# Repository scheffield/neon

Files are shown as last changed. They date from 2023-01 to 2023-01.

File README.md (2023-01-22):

# Neon

Neon is a remote controllable RGB light meant for video shots and life streaming. It's build around the ESP32-S2 and addressable RGB lights like the WS2812 or SK6812. This repository contains all the files to build your own version.

If you haven't go check out the build and some more info in this YouTube video:

Neon YouTube video (http://www.youtube.com/watch?v=w3ysH9Jxcy4 "Neon | PCB design, CAD and Code")

## Directory structure
```
$project_root/
├── cad/ ........... open with Fusion360
├── code/
│   ├── baords/ .... board config
│   ├── data/ ...... compiled website
│   ├── src/ ....... code for ESP32
│   ├── variants ... particion table
│   └── web/ ....... web UI
├── pcb/ ........... open with KiCad
└── stl/ ........... for 3D printing
```

## Web UI

### setup
```bash
cd web
npm i
```

### develop
```bash
npm run dev
```

### build
```bash
npm run webpack
cp dist/index.html ../data
pio run --target uploadfs
```

The last step is assuming that PlatformIO is installed and available as `pio`.

## BOM
Appart from the BOM for the PCB which can be exported from KiCad, the following parts are needed:

**BOM**
| Part | Amount |
|---|---|
| [1/4"*20 Threaded Heat Set Inserts](https://www.amazon.com.au/dp/B077P4M1CM) | 1 |
| [3-pin LiPo Battery 6000mAh](https://core-electronics.com.au/3-pin-lipo-battery-for-pijuice-6000mah.html) | 1 |

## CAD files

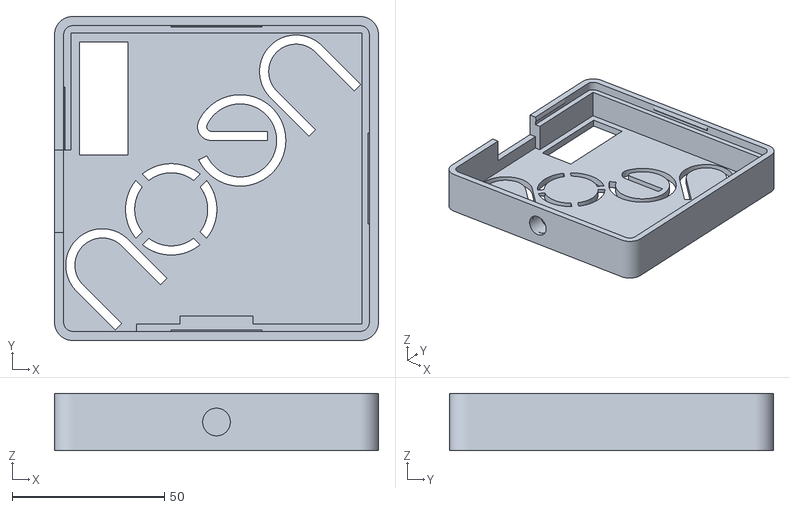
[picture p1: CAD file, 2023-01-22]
stl/case.stl
106.4 x 106.4 x 18.9

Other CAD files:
cad/neon.f3z

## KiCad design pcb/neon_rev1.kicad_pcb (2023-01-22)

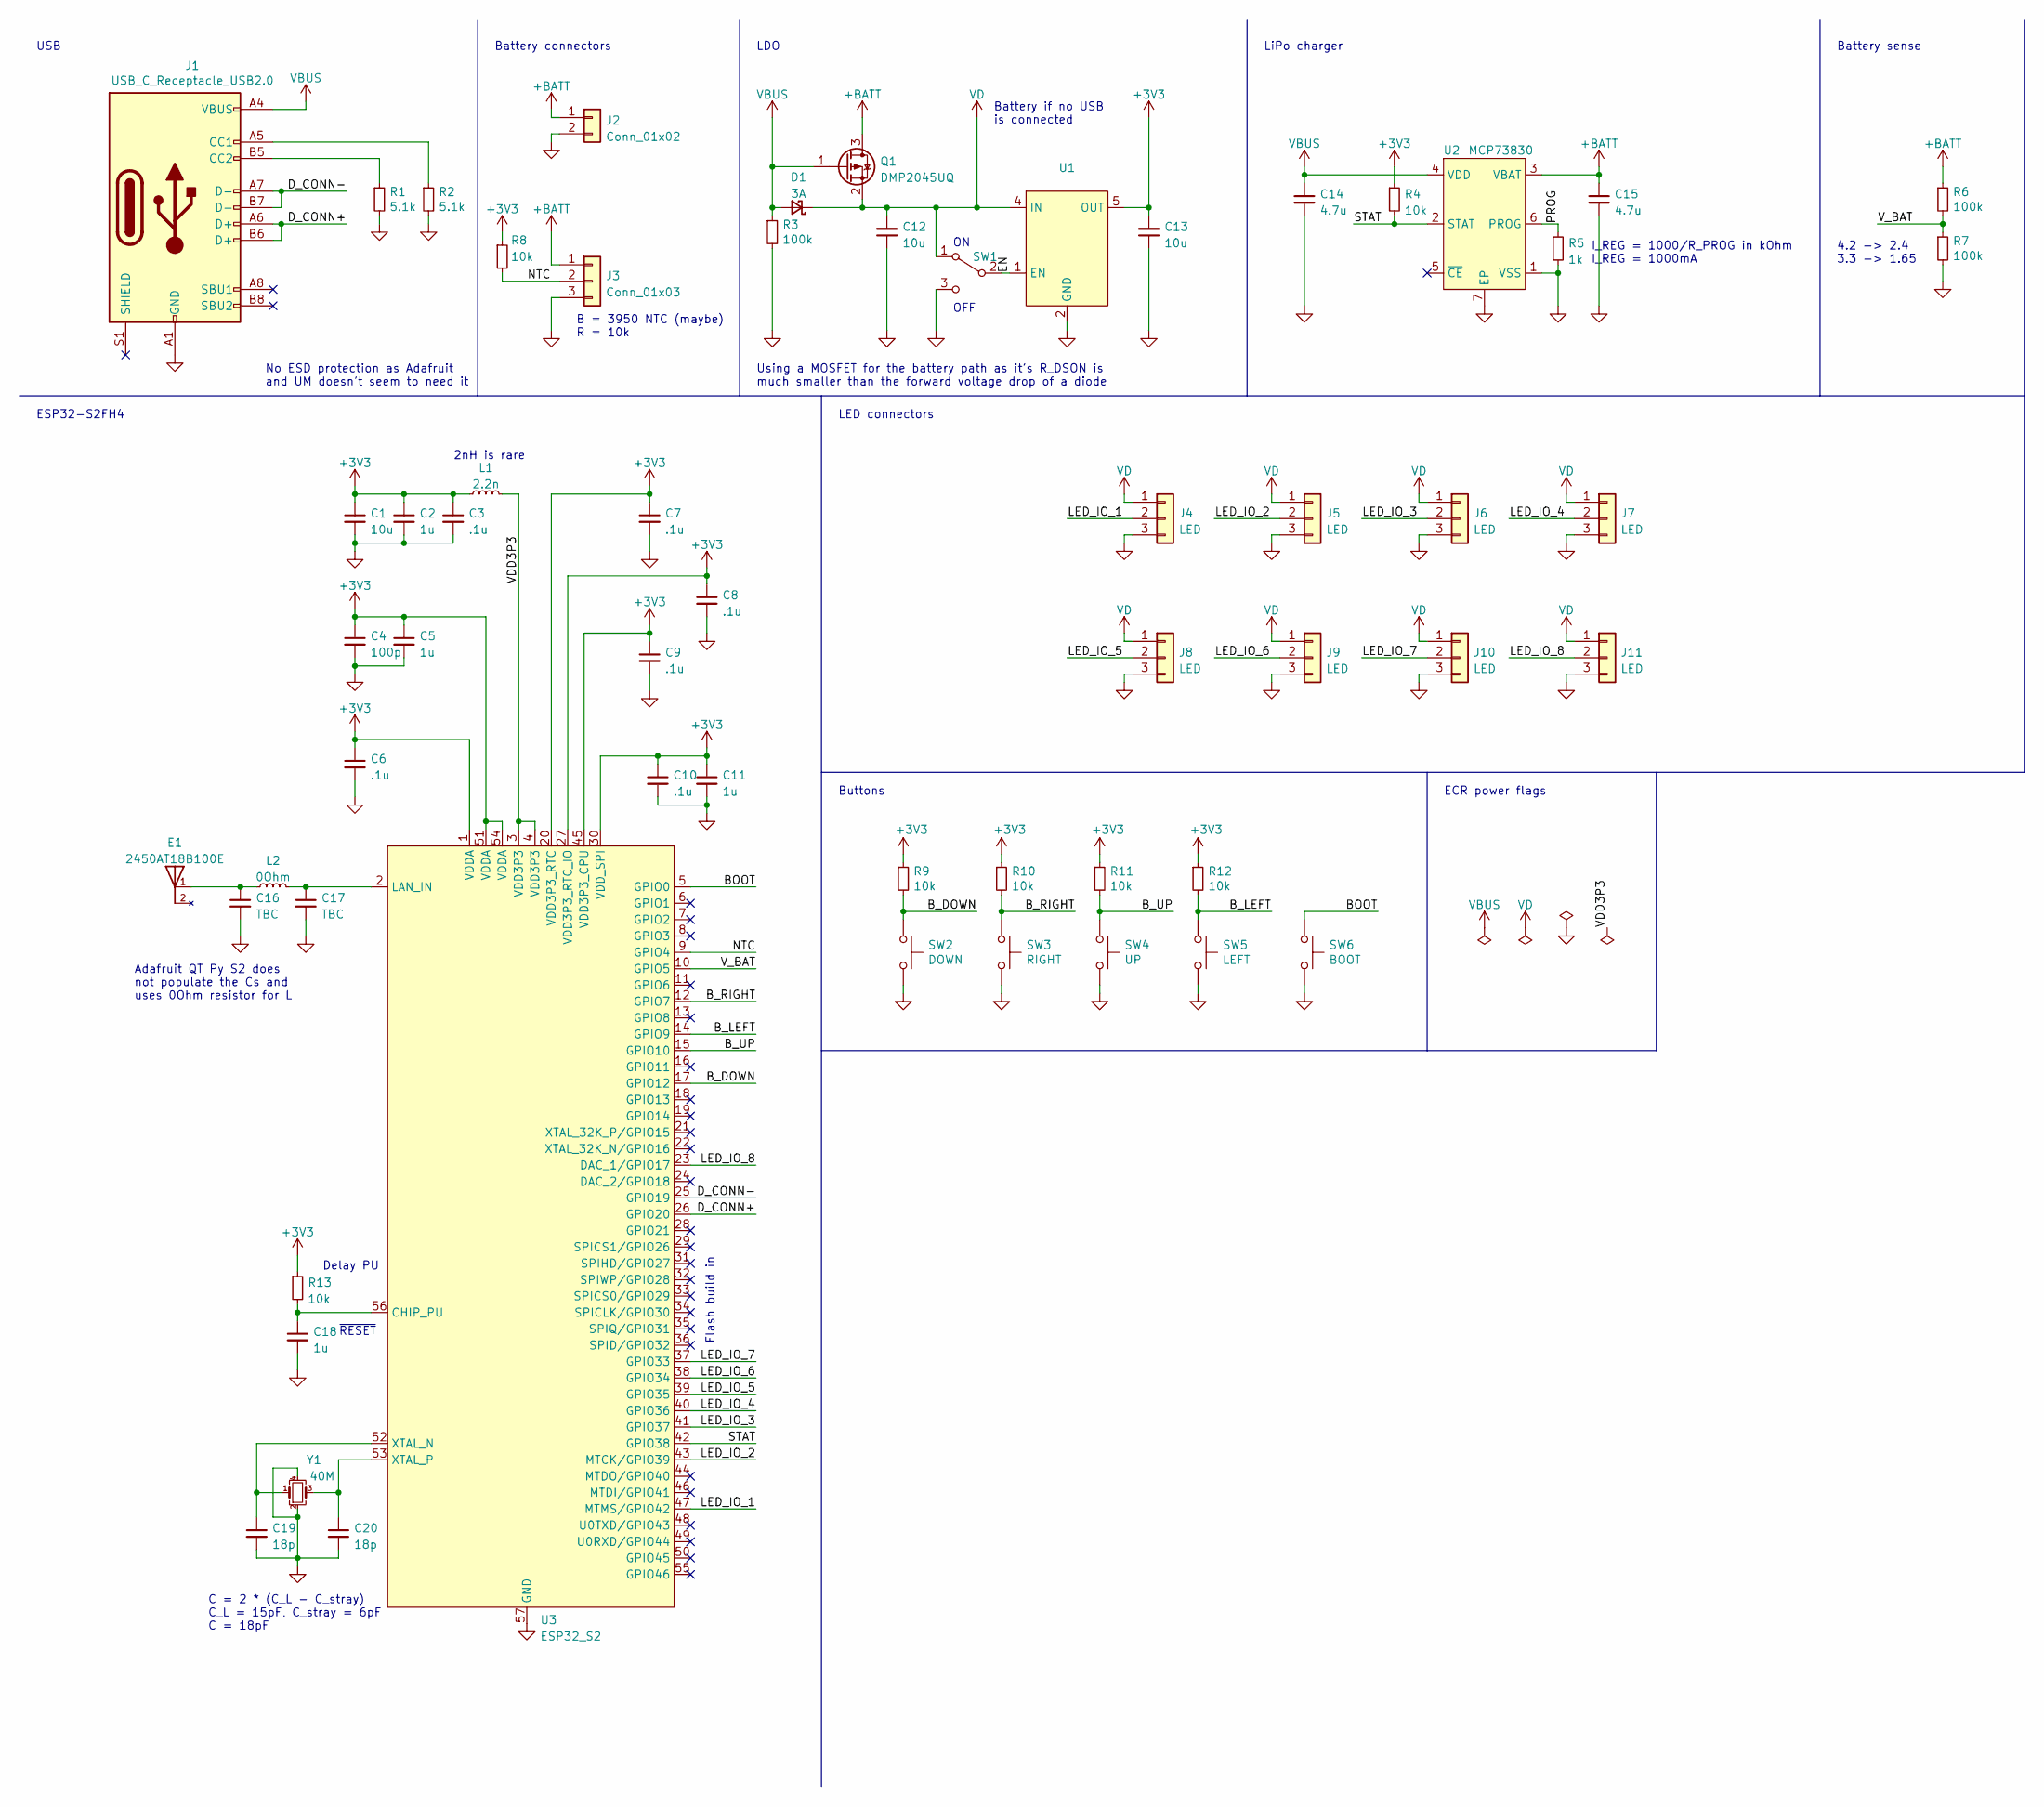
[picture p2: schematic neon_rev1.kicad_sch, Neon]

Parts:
C1, C12, C13: 10u; C_0603_1608Metric
C2, C5, C11, C18: 1u; C_0603_1608Metric
C3, C6, C7, C8, C9, C10: .1u; C_0603_1608Metric
C4: 100p; C_0603_1608Metric
C14, C15: 4.7u; C_0603_1608Metric
C16, C17: TBC; C_0402_1005Metric
C19, C20: 18p; C_0603_1608Metric
D1: 3A; D_PowerDI-123
E1: 2450AT18B100E; XDCR_2450AT18B100E; PARTREV 4.0
J1: USB_C_Receptacle_USB2.0; USB_C_Receptacle_Palconn_UTC16-G
J2: Conn_01x02; JST_PH_S2B-PH-SM4-TB_1x02-1MP_P2.00mm_Horizontal
J3: Conn_01x03; JST_PH_S3B-PH-SM4-TB_1x03-1MP_P2.00mm_Horizontal
J4, J5, J6, J7, J8, J9, J10, J11: LED; LED_strip
L1: 2.2n; L_0603_1608Metric
L2: 0Ohm; L_0402_1005Metric
Q1: DMP2045UQ; SOT-23
R1, R2: 5.1k; R_0603_1608Metric
R3, R6, R7: 100k; R_0603_1608Metric
R4, R8, R9, R10, R11, R12, R13: 10k; R_0603_1608Metric
R5: 1k; R_0603_1608Metric
SW1: POWER; SW_SPDT_CK-JS102011SAQN
SW2: DOWN; SW_SPST_PTS645
SW3: RIGHT; SW_SPST_PTS645
SW4: UP; SW_SPST_PTS645
SW5: LEFT; SW_SPST_PTS645
SW6: BOOT; SW_SPST_PTS815
U1: (no value)
U2: MCP73830; TDFN-6-1EP_2x2mm_P0.5mm_EP0.6x1.6mm
U3: ESP32_S2; ESP32-S2
Y1: 40M; Crystal_SMD_3225-4Pin_3.2x2.5mm

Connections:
+3V3: C1.1, C2.1, C3.1, C4.1, C5.1, C6.1, C7.1, C8.1, C9.1, C10.1, C11.1, C13.2, L1.1, R4.1, R8.1, R9.1, R10.1, R11.1, R12.1, R13.1, U1.5 (OUT), U3.1 (VDDA), U3.20 (VDD3P3_RTC), U3.27 (VDD3P3_RTC_IO), U3.30 (VDD_SPI), U3.45 (VDD3P3_CPU), U3.51 (VDDA), U3.54 (VDDA)
+BATT: C15.1, J2.1, J3.1, Q1.3 (D), R6.1, U2.3 (VBAT)
/BOOT: SW6.1, U3.5 (GPIO0)
/B_DOWN: R9.2, SW2.1, U3.17 (GPIO12)
/B_LEFT: R12.2, SW5.1, U3.14 (GPIO9)
/B_RIGHT: R10.2, SW3.1, U3.12 (GPIO7)
/B_UP: R11.2, SW4.1, U3.15 (GPIO10)
/D_CONN+: J1.A6 (D+), J1.B6 (D+), U3.26 (GPIO20)
/D_CONN-: J1.A7 (D-), J1.B7 (D-), U3.25 (GPIO19)
/EN: SW1.2 (B), U1.1 (EN)
/LED_IO_1: J4.2, U3.47 (MTMS/GPIO42)
/LED_IO_2: J5.2, U3.43 (MTCK/GPIO39)
/LED_IO_3: J6.2, U3.41 (GPIO37)
/LED_IO_4: J7.2, U3.40 (GPIO36)
/LED_IO_5: J8.2, U3.39 (GPIO35)
/LED_IO_6: J9.2, U3.38 (GPIO34)
/LED_IO_7: J10.2, U3.37 (GPIO33)
/LED_IO_8: J11.2, U3.23 (DAC_1/GPIO17)
/NTC: J3.2, R8.2, U3.9 (GPIO4)
/PROG: R5.1, U2.6 (PROG)
/STAT: R4.2, U2.2 (STAT), U3.42 (GPIO38)
/VDD3P3: L1.2, U3.3 (VDD3P3), U3.4 (VDD3P3)
/V_BAT: R6.2, R7.1, U3.10 (GPIO5)
GND: C1.2, C2.2, C3.2, C4.2, C5.2, C6.2, C7.2, C8.2, C9.2, C10.2, C11.2, C12.1, C13.1, C14.2, C15.2, C16.2, C17.2, C18.2, C19.2, C20.2, J1.A1 (GND), J1.A12 (GND), J1.B1 (GND), J1.B12 (GND), J2.2, J3.3, J4.3, J5.3, J6.3, J7.3, J8.3, J9.3, J10.3, J11.3, R1.2, R2.2, R3.2, R5.2, R7.2, SW1.3 (C), SW2.2, SW3.2, SW4.2, SW5.2, SW6.2, U1.2 (GND), U2.1 (VSS), U2.7 (EP), U3.57 (GND), Y1.2, Y1.4
unnamed: C16.1, E1.1, L2.1
unnamed: C17.1, L2.2, U3.2 (LAN_IN)
unnamed: C18.1, R13.2, U3.56 (CHIP_PU)
unnamed: C19.1, U3.52 (XTAL_N), Y1.1
unnamed: C20.1, U3.53 (XTAL_P), Y1.3
unnamed: J1.A5 (CC1), R2.1
unnamed: J1.B5 (CC2), R1.1
VBUS: C14.1, D1.2 (A), J1.A4 (VBUS), J1.A9 (VBUS), J1.B4 (VBUS), J1.B9 (VBUS), Q1.1 (G), R3.1, U2.4 (VDD)
VD: C12.2, D1.1 (K), J4.1, J5.1, J6.1, J7.1, J8.1, J9.1, J10.1, J11.1, Q1.2 (S), SW1.1 (A), U1.4 (IN)

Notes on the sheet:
4.2 -> 2.4 3.3 -> 1.65
Battery sense
ECR power flags
~{RESET}
Flash build in
Battery if no USB is connected
LDO
LED connectors
I_REG = 1000/R_PROG in kOhm I_REG = 1000mA
Battery connectors
Using a MOSFET for the battery path as it's R_DSON is much smaller than the forward voltage drop of a diode
OFF
ESP32-S2FH4
2nH is rare
Buttons
LiPo charger
B = 3950 NTC (maybe) R = 10k
No ESD protection as Adafruit and UM doesn't seem to need it
USB
C = 2 * (C_L - C_stray) C_L = 15pF, C_stray = 6pF C = 18pF
Adafruit QT Py S2 does not populate the Cs and uses 0Ohm resistor for L
Delay PU

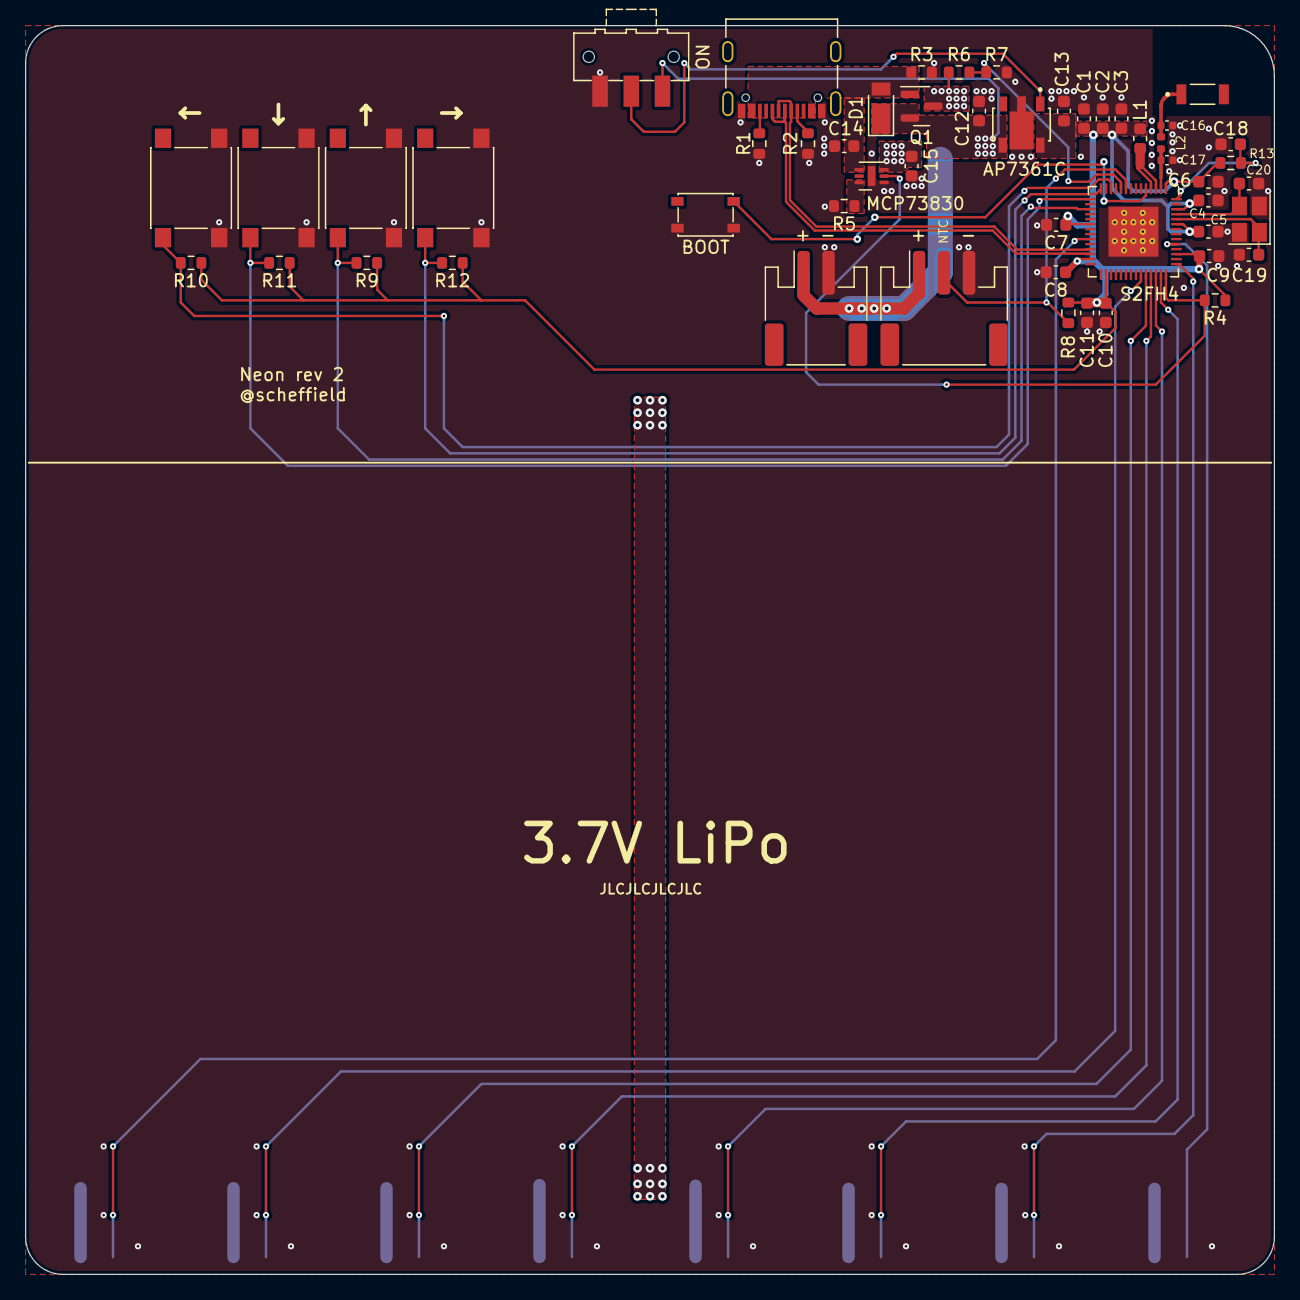
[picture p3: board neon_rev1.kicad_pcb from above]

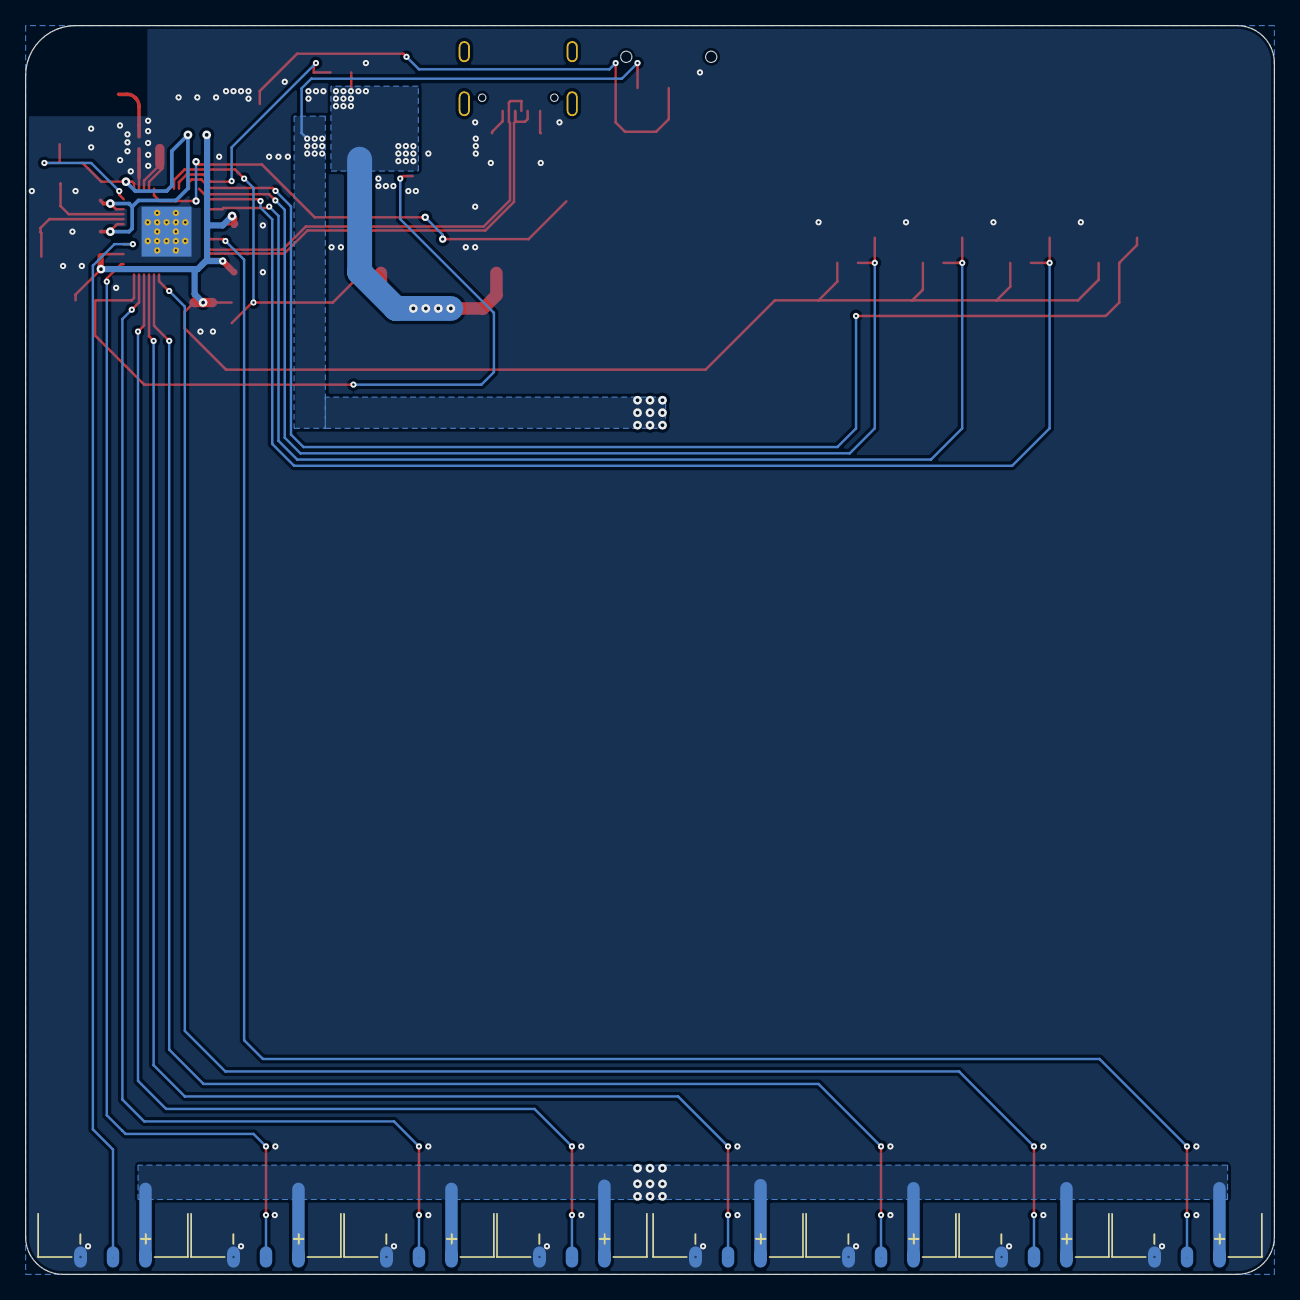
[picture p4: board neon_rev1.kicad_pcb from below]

Board: 4 copper layers, 100.0 x 100.0 mm, 59 parts (8 on the bottom side), 33 nets.

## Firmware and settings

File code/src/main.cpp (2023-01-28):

#include <Arduino.h>
#include <Adafruit_NeoPixel.h>
#include <WiFi.h>
#include "FFat.h"
#include <ESPAsyncWebServer.h>
#include "AsyncJson.h"
#include "ArduinoJson.h"
#include <Preferences.h>
#include <ESPmDNS.h>
#include <Adafruit_GFX.h>

const uint8_t LED_COUNT = 14;
const neoPixelType TYPE = NEO_RGBW + NEO_KHZ800;

const uint8_t BUTTON_UP = 10;
const uint8_t BUTTON_LEFT = 9;
const uint8_t BUTTON_RIGHT = 7;
const uint8_t BUTTON_DOWN = 12;
const uint8_t VBAT = 5;
const uint8_t NTC = 4;
const uint8_t STAT = 38;
const uint8_t LED1 = 42;
const uint8_t LED2 = 39;
const uint8_t LED3 = 37;
const uint8_t LED4 = 36;
const uint8_t LED5 = 35;
const uint8_t LED6 = 34;
const uint8_t LED7 = 33;
const uint8_t LED8 = 17;

const uint32_t THERMISTORNOMINAL = 10000;
// temp. for nominal resistance (almost always 25 C)
const uint8_t TEMPERATURENOMINAL = 25;
// The beta coefficient of the thermistor (usually 3000-4000)
const uint16_t BCOEFFICIENT = 3950; // most likely wrong
// the value of the 'other' resistor
const uint16_t SERIESRESISTOR = 10000;


const uint32_t colors[] = {0x00FF0000, 0x00FFFF00, 0x0000FF00, 0x0000FFFF, 0x000000FF, 0x00FF00FF, 0x00FFFFFF};
const uint8_t colorsCount = 7;

const uint8_t brightnesses[] = {0, /*1, 3, */7, 15, 31, 63, 127, 255};
const uint8_t brightnessesCount = 7;

// to deal with negative k. from: https://stackoverflow.com/a/23214219
int mod(int k, int n) {
  return ((k %= n) < 0) ? k+n : k;
}

float easeInQuad(const float x) {
  return x * x;
}

// -- color helper ------------------------------------------------------------
uint16_t convertRGB888toRGB565(uint8_t r8, uint8_t g8, uint8_t b8) {
  // from https://developer.apple.com/documentation/accelerate/1533044-vimageconvert_argb8888torgb565
  uint32_t r5 = (r8   * (31*2) + 255) / (255*2);
  uint32_t g6 = (g8 * 63 + 127) / 255;
  uint32_t b5 = (b8  * 31 + 127) / 255;
  // Serial.printf("convertRGB888toRGB565; r8: %d, r5: %d, g8: %d, g6: %d, b8: %d, b5: %d\n", r8, r5, g8, g6, b8, b5);
  return (r5 << 11) | (g6 <<  5) | b5;
}

uint16_t convertRGB888toRGB565(uint32_t in) {
  uint8_t r8 = (uint8_t)(in >> 16);
  uint8_t g8 = (uint8_t)(in >> 8);
  uint8_t b8 = (uint8_t)in;
  return convertRGB888toRGB565(r8, g8, b8);
}

uint32_t convertRGB565toARGB888(uint16_t in) {
  // bitmasks are needed as the values don't line up nicely with uint8_t
  // from https://stackoverflow.com/questions/2442576/how-does-one-convert-16-bit-rgb565-to-24-bit-rgb888
  uint8_t r5 = (uint8_t)((in & 0xf800) >> 11);
  uint8_t g6 = (uint8_t)((in & 0x07e0) >> 5);
  uint8_t b5 = (uint8_t)in & 0x001f;
  // from https://developer.apple.com/documentation/accelerate/1533159-vimageconvert_rgb565toargb8888
  uint32_t r8 = (r5 * 255 + 15) / 31;
  uint32_t g8 = (g6 * 255 + 31) / 63;
  uint32_t b8 = (b5 * 255 + 15) / 31;
  // Serial.printf("convertRGB565toARGB888; r8: %d, r5: %d, g8: %d, g6: %d, b8: %d, b5: %d\n", r8, r5, g8, g6, b8, b5);
  return (r8 << 16) | (g8 <<  8) | b8;
}

// -- NeoPixel matrix ---------------------------------------------------------

typedef enum {
  NEON_ANIMATION_NONE = 1,
  NEON_ANIMATION_CIRCLE_FROM_CENTER = 2,
  NEON_ANIMATION_CIRCLE_FROM_SWITCH = 3,
  NEON_ANIMATION_BREATH_CONFIGURED = 4,
  NEON_ANIMATION_BREATH_NO_WIFI = 5,
  NEON_ANIMATION_CIRCLE_CONFIG_WIFI = 6,
} Animation;

class NeonMatrix : public Adafruit_GFX {
  private: 
    Adafruit_NeoPixel* _strips[8];
    uint8_t _brightness = 0;
    uint8_t _r = 255;
    uint8_t _g = 255;
    uint8_t _b = 255;
    uint8_t _transaction = 0;
    Animation _animation = NEON_ANIMATION_NONE;
    Animation _nextAnimation = NEON_ANIMATION_NONE;
    unsigned long _animationStartedAt = 0;
    float _animationProgress = 0;
    unsigned long _lastFastIntervalMs = 0;

    float easeInOutSine(const float x) {
      // from https://easings.net/#easeInOutSine
      return -(cos(PI * x) - 1) / 2;
    }

    void nextAnimation() {
      if (_nextAnimation == NEON_ANIMATION_NONE) {
        return;
      }
      _animation = _nextAnimation;
      _nextAnimation = NEON_ANIMATION_NONE;
      _animationProgress = 0;
      _animationStartedAt = 0;
    }

    void stepAnimation() {
      if (_animation == NEON_ANIMATION_NONE) {
        return;
      }
      
      const auto now = millis();
      if (_animationStartedAt == 0) {
        _animationStartedAt = now;
      }
      
      if (_animation == NEON_ANIMATION_CIRCLE_FROM_CENTER) {
        const uint16_t currentRadius = _animationProgress * 12;
        _animationProgress = fmod((now - _animationStartedAt) / 1000.0, 1);
        const uint16_t nextRadius = _animationProgress * 12;
        if (currentRadius == nextRadius) {
          return;
        }
        startWrite();
        drawCircle(6, 6, currentRadius, 0);
        drawCircle(6, 6, nextRadius, convertRGB888toRGB565(255, 255, 0));
        endWrite();
      } else if (_animation == NEON_ANIMATION_CIRCLE_FROM_SWITCH) {
        const uint16_t currentRadius = _animationProgress * 18;
        _animationProgress = (now - _animationStartedAt) / 500.0;
        if (_animationProgress > 1) {
          nextAnimation();
          return;
        }
        const uint16_t nextRadius = _animationProgress * 18;
        if (currentRadius == nextRadius) {
          return;
        }
        startWrite();
        for (int8_t i = -2; i <= 2; i++) {
          drawCircle(8, 13, currentRadius + i, 0);
        }
        for (int8_t i = -2; i <= 2; i++) {
          const float brightness = pow((2 - abs(i)) / 2., 3);
          drawCircle(8, 13, nextRadius + i, convertRGB888toRGB565(255 * brightness, 255 * brightness, 0));
        }
        endWrite();
      } else if (_animation == NEON_ANIMATION_BREATH_CONFIGURED) {
        _animationProgress = fmod((now - _animationStartedAt) / 2000.0, 1);
        float brightness = easeInOutSine(1 - (abs(_animationProgress - 0.5) * 2));
        drawPixel(8, 13, convertRGB888toRGB565(0, 255 * brightness, 0));
      } else if (_animation == NEON_ANIMATION_BREATH_NO_WIFI) {
        _animationProgress = fmod((now - _animationStartedAt) / 2000.0, 1);
        float brightness = easeInOutSine(1 - (abs(_animationProgress - 0.5) * 2));
        drawPixel(8, 13, convertRGB888toRGB565(255 * brightness, 0, 0));
      } else if (_animation == NEON_ANIMATION_CIRCLE_CONFIG_WIFI) {
        const uint16_t currentRadius = _animationProgress * 12;
        _animationProgress = fmod((now - _animationStartedAt) / 1000.0, 1);
        const uint16_t nextRadius = _animationProgress * 12;
        if (currentRadius == nextRadius) {
          return;
        }
        startWrite();
        for (int8_t i = -2; i <= 2; i++) {
          drawCircle(6, 6, currentRadius + i, 0);
        }
        for (int8_t i = -2; i <= 2; i++) {
          const float brightness = pow((2 - abs(i)) / 2., 3);
          drawCircle(6, 6, nextRadius + i, convertRGB888toRGB565(0, 0, 255 * brightness));
        }
        endWrite();
      }
    }

  public:
    NeonMatrix() : Adafruit_GFX(8 * 2, 14), _strips{
      new Adafruit_NeoPixel(LED_COUNT, LED1, TYPE),
      new Adafruit_NeoPixel(LED_COUNT, LED2, TYPE),
      new Adafruit_NeoPixel(LED_COUNT, LED3, TYPE),
      new Adafruit_NeoPixel(LED_COUNT, LED4, TYPE),
      new Adafruit_NeoPixel(LED_COUNT, LED5, TYPE),
      new Adafruit_NeoPixel(LED_COUNT, LED6, TYPE),
      new Adafruit_NeoPixel(LED_COUNT, LED7, TYPE),
      new Adafruit_NeoPixel(LED_COUNT, LED8, TYPE),
    } {}

    void begin() {
      for (int i = 0; i < 8; i++) {
        Adafruit_NeoPixel* strip = _strips[i];
        strip->begin();
        strip->show(); // Initialize all pixels to 'off'
      }
    }

    void drawPixel(int16_t x, int16_t y, const uint16_t color) {
      // Serial.printf("x: %d, y: %d, color: %d\n", x, y, color);
      if (x % 2 == 1 || x < 0 || x >= width() || y < 0 || y >= height()) {
        return;
      }
      x = x / 2;
      Adafruit_NeoPixel* strip = _strips[x];
      // TODO: GFX only works with RGB565, do we lose anything?
      strip->setPixelColor(y, convertRGB565toARGB888(color));
      if (!_transaction) {
        strip->show();
      }
    }

    void startWrite() {
      _transaction++;
    }

    void endWrite() {
      _transaction--;
      if (_transaction) {
        return;
      }
      for (int i = 0; i < 8; i++) {
        Adafruit_NeoPixel* strip = _strips[i];
        strip->show();
      }
    }

    uint8_t getBrightness() {
      return _brightness;
    }

    void setBrightness(const uint8_t brightness) {
      if (_brightness == brightness) {
        return;
      }
      _brightness = brightness;
      setAnimation(NEON_ANIMATION_NONE);
      fillScreen(convertRGB888toRGB565(
        (_r * _brightness) >> 8,
        (_g * _brightness) >> 8,
        (_b * _brightness) >> 8
      ));
    }

    uint8_t getR() {
      return _r;
    }

    uint8_t getG() {
      return _g;
    }

    uint8_t getB() {
      return _b;
    }

    void setColor(const uint32_t c) {
      uint8_t r = (uint8_t)(c >> 16);
      uint8_t g = (uint8_t)(c >> 8);
      uint8_t b = (uint8_t)c;
      setColor(r, g, b);
    }

    void setColor(const uint8_t r, const uint8_t g, const uint8_t b) {
      if (_r == r && _g == g && _b == b) {
        return;
      }
      _r = r;
      _g = g;
      _b = b;
      setAnimation(NEON_ANIMATION_NONE);
      fillScreen(convertRGB888toRGB565(
        (_r * _brightness) >> 8,
        (_g * _brightness) >> 8,
        (_b * _brightness) >> 8
      ));
    }

    void loop() {
      const unsigned long current = millis();

      if (current - _lastFastIntervalMs >= 50) {
        _lastFastIntervalMs = current;
        stepAnimation();
      }
    }

    void setAnimation(Animation animation) {
      _animation = animation;
      if (_animation != NEON_ANIMATION_NONE) {
        setBrightness(0);
      }
    }

    void setNextAnimation(Animation animation) {
      if (_animation == NEON_ANIMATION_NONE) {
        _animation = animation;
      } else {
        _nextAnimation = animation;
      }
    }
};

NeonMatrix matrix = NeonMatrix();

typedef enum {
  NEON_UNCONNECTED = 0,
  NEON_CONNECTING = 1,
  NEON_CONNECTED = 2,
  NEON_PAIRING = 3,
  NEON_PAIRING_CONNECTING = 4,
  NEON_PAIRING_SUCCESS = 5,
} WifiState;

struct State {
  float battery = 0;
  bool charging = false;
  float cpuTemp = 0;
  float batteryTemp = 0;
  long upPressedAt = 0;
  long downPressedAt = 0;
  long leftPressedAt = 0;
  long rightPressedAt = 0;

  WifiState wifiState = NEON_UNCONNECTED;
  String tmpSsid = String();
  String tmpPassword = String();
  long wifiConnectingSince = 0;

  int8_t currentColor = 0;
  int8_t currentBrightness = 0;
} _state;

AsyncWebServer server(80);

Preferences preferences;

typedef enum {
  NEON_BUTTON_NONE = 1,
  NEON_BUTTON_SHORT = 2,
  NEON_BUTTON_LONG = 3,
} ButtonPress;

ButtonPress handleButton(const uint8_t pin, long& pressedAt) {
  bool signal = !digitalRead(pin); // pulled up, normally high
  const long current = millis();
  if (signal) {
    if (pressedAt == 0) {
      pressedAt = current;
    }
  } else {
    ButtonPress res;
    if (pressedAt != 0) {
      if (current - pressedAt >= 1000) {
        res = NEON_BUTTON_LONG;
      } else {
        res = NEON_BUTTON_SHORT;
      }
      pressedAt = 0;
      return res;
    }
  }
  return NEON_BUTTON_NONE;
}

// Allow when in pairing mode
bool filterOnPairing(AsyncWebServerRequest *request) { 
  return _state.wifiState == NEON_PAIRING
      || _state.wifiState == NEON_PAIRING_CONNECTING
      || _state.wifiState == NEON_PAIRING_SUCCESS;
  }

// -- Wifi State Machine / helpers --------------------------------------------
struct WifiConfig {
  const String ssid;
  const String password;
};

typedef enum {
  NEON_FAILED = 1,
  NEON_WAITING = 2,
  NEON_SUCCESS = 3,
} WifiCheckResult;

// -- Wifi State Machine / side effects ---------------------------------------
WifiConfig readWifiPreferences() {
  return WifiConfig{
    preferences.getString("ssid"),
    preferences.getString("password"),
  };
}

void writeWifiPreferences(const WifiConfig config) {
  preferences.putString("ssid", config.ssid);
  preferences.putString("password", config.password);
}

WifiConfig readTmpWifiPreferences() {
  return WifiConfig{
    _state.tmpSsid,
    _state.tmpPassword,
  };
}

void writeTmpWifiPreferences(const WifiConfig config) {
  _state.tmpSsid = config.ssid;
  _state.tmpPassword = config.password;
}

void connectToWifi(const WifiConfig config) {
  Serial.printf("Connecting to ssid: %s\n", config.ssid);
  WiFi.setHostname("Neon");
  WiFi.begin(config.ssid.c_str(), config.password.c_str());
  _state.wifiConnectingSince = millis();
}

void startMdns() {
  if(!MDNS.begin("neon")) {
    Serial.println("Error starting mDNS");
  }
}

WifiCheckResult checkConnectedWithTimeout() {
  if (WiFi.status() == WL_CONNECTED) {
    return NEON_SUCCESS;
  }
  if (millis() - _state.wifiConnectingSince >= 10000) {
    Serial.println("Failed to connect to Wifi");
    return NEON_FAILED;
  }
  return NEON_WAITING;
}

void startServer() {
  server.begin();
}

void startAp() {
  WiFi.softAP("Neon Setup");
}

void stopAp() {
  WiFi.softAPdisconnect();
}

// -- Wifi State Machine / actions --------------------------------------------
void connectWifi() {
  if (_state.wifiState != NEON_UNCONNECTED) {
    return;
  }

  const auto config = readWifiPreferences();
  if (config.ssid.isEmpty()) {
    Serial.println("No wifi ssid configured");
    return;
  }
  
  connectToWifi(config);

  _state.wifiState = NEON_CONNECTING;
}

void checkWifi() {
  if (_state.wifiState != NEON_CONNECTING) {
    return;
  }

  const auto res = checkConnectedWithTimeout();
  if (res == NEON_SUCCESS) {
    startServer();
    startMdns();
    matrix.setAnimation(NEON_ANIMATION_BREATH_CONFIGURED);
    _state.wifiState = NEON_CONNECTED;
  } else if (res == NEON_FAILED) {
    _state.wifiState = NEON_UNCONNECTED;
  }
}

// void disconnectWifi() {}

void startPairing() {
  if (_state.wifiState != NEON_UNCONNECTED && _state.wifiState != NEON_CONNECTING && _state.wifiState != NEON_CONNECTED) {
    return;
  }

  startAp();
  startServer();
  matrix.setAnimation(NEON_ANIMATION_CIRCLE_CONFIG_WIFI);

  _state.wifiState = NEON_PAIRING;
}

void updateWifi(const String ssid, const String password) {
  if (_state.wifiState != NEON_PAIRING) {
    return;
  }

  const auto config = WifiConfig{ssid, password};
  writeTmpWifiPreferences(config);
  connectToWifi(config);
  Serial.println("updateWifi; connecting done");

  _state.wifiState = NEON_PAIRING_CONNECTING;
}

void checkPairing() {
  if (_state.wifiState != NEON_PAIRING_CONNECTING) {
    return;
  }

  const auto res = checkConnectedWithTimeout();
  if (res == NEON_SUCCESS) {
    writeWifiPreferences(readTmpWifiPreferences());
    startMdns();
    matrix.setAnimation(NEON_ANIMATION_BREATH_CONFIGURED);
    _state.wifiState = NEON_PAIRING_SUCCESS;
  } else if (res == NEON_FAILED) {
    _state.wifiState = NEON_PAIRING;
  }
}

void pairingSuccessMessaged() {
  if (_state.wifiState != NEON_PAIRING_SUCCESS) {
    return;
  }

  stopAp();

  _state.wifiState = NEON_CONNECTED;
}

String wifiStateToString() {
       if (_state.wifiState == NEON_UNCONNECTED) {return "NEON_UNCONNECTED";}
  else if (_state.wifiState == NEON_CONNECTING) {return "NEON_CONNECTING";}
  else if (_state.wifiState == NEON_CONNECTED) {return "NEON_CONNECTED";}
  else if (_state.wifiState == NEON_PAIRING) {return "NEON_PAIRING";}
  else if (_state.wifiState == NEON_PAIRING_CONNECTING) {return "NEON_PAIRING_CONNECTING";}
  else if (_state.wifiState == NEON_PAIRING_SUCCESS) {return "NEON_PAIRING_SUCCESS";}
  return "unknown state";
}

void writeStateToResponse(AsyncResponseStream *response) {
  DynamicJsonBuffer jsonBuffer;
  JsonObject &root = jsonBuffer.createObject();
  root["brightness"] = matrix.getBrightness();
  root["r"] = matrix.getR();
  root["g"] = matrix.getG();
  root["b"] = matrix.getB();
  root["battery"] = _state.battery;
  root["charging"] = _state.charging;
  root["cpuTemp"] = _state.cpuTemp;
  root["batteryTemp"] = _state.batteryTemp;
  root.printTo(*response);
}

template <typename TString, typename TValue>
bool maybeUpdateStateFromJson(JsonObject& jsonObj, TString* key, TValue& current) {
  if (jsonObj.containsKey(key)) {
    uint8_t value = jsonObj[key];
    if (current != value) {
      current = value;
      return true;
    }
  }
  return false;
}

bool maybeUpdateStateFromJson(JsonObject& jsonObj, String key, uint8_t (*get)(), void (*set)(uint8_t)) {
  if (jsonObj.containsKey(key)) {
    uint8_t value = jsonObj[key];
    if (get() != value) {
      set(value);
      return true;
    }
  }
  return false;
}
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
void loop() {
  matrix.loop();
  unsigned long current = millis();

  if (current - _lastFastIntervalMs >= 100) {
    _lastFastIntervalMs = current;
    const auto up = handleButton(BUTTON_UP, _state.upPressedAt);
    if (up == NEON_BUTTON_LONG) {
      startPairing();
    } else if (up == NEON_BUTTON_SHORT) {
      _state.currentBrightness = constrain(_state.currentBrightness + 1, 0, brightnessesCount - 1);
      matrix.setBrightness(brightnesses[_state.currentBrightness]);
    }
    if (handleButton(BUTTON_DOWN, _state.downPressedAt) == NEON_BUTTON_SHORT) {
      _state.currentBrightness = constrain(_state.currentBrightness - 1, 0, brightnessesCount - 1);
      matrix.setBrightness(brightnesses[_state.currentBrightness]);
    }
    if (handleButton(BUTTON_LEFT, _state.leftPressedAt) == NEON_BUTTON_SHORT) {
      _state.currentColor = mod(_state.currentColor + 1, colorsCount);
      matrix.setColor(colors[_state.currentColor]);
      if (matrix.getBrightness() == 0) {
        matrix.setBrightness(31);
        _state.currentBrightness = 3;
      }
    }
    if (handleButton(BUTTON_RIGHT, _state.rightPressedAt) == NEON_BUTTON_SHORT) {
      _state.currentColor = mod(_state.currentColor - 1, colorsCount);
      matrix.setColor(colors[_state.currentColor]);
      if (matrix.getBrightness() == 0) {
        matrix.setBrightness(31);
        _state.currentBrightness = 3;
      }
    }
  }
  if (current - _lastSlowIntervalMs >= 2000) {
    _lastSlowIntervalMs = current;
    checkWifi();
    checkPairing();
    updateSensorState();
    Serial.printf("vBat: %1.2f, ntc: %f, stat: %d, ap ip: %s, sta ip: %s, rssi: %d, status: %s\n", _state.battery, _state.batteryTemp, _state.charging, WiFi.softAPIP().toString(), WiFi.localIP().toString(), WiFi.RSSI(), wifiStateToString().c_str());
  }
}
